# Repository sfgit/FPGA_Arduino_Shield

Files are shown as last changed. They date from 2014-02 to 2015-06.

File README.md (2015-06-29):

FPGA_Arduino_Shield
===================

**WIP** FPGA-based shield for Arduino (Standard UNO Connector pinout should support any Arduino with similar pinout)

NOTE:  It is my intent that the final design will work independently from the Arduino, so an Arduino would not be required to explore FPGA awesomeness.  That said, you may require a JTAG programmer or other device to program the SPI flash on the board.  Target pricing for this board is $30.  

Project Details:

This project is an effort to build a Xilinx Spartan 6 LX9 FPGA "shield" for the various 
Arduino development boards.  This board will also stand-alone, thus you will not require
the arduino to program and play with the FPGA.  

From the top level, the FPGA uses SPI configuration flash for it's in-system programming.
Also JTAG.  Thus if you program the flash, reboot the FPGA, it will load its config via
the flash.  This enables in-system, "asynchronous" reprogramming out-of-step with 
the overall system (arduino can keep running, as can any peripherals that are not a part
of the FPGA itself or FPGA subsystem).  This is super cool because it means that you might then 
use something like an SDCard or even TCP/IP comms to download new "hardware" configurations to
the FPGA and deploy them.  Thus, it may be possible to truly deploy new hardware remotely without
the need to crack into the case.  Awesomeness.  

In its simplest form this is the ultimate Arduino IO expander.  At it's most sophisticated, the
fpga has the capability to run it's own processor(s), it's own peripherals, and serve as its 
own system (the FPGA becoming the more prominent part of the system).  FPGAs are great for complex
parallel operations including DSP operations, audio, video, bitminer, etc. that an OTS CPU may not 
be suited for.  

Project details are available at:  hackaday.io/matt and the design files are starting
to trickle in here.  Regular revisions to the schematics are rolling in as changes are made and 
the structure of the project may change dramatically over time.  This means some design files 
may vanish.  If you need access to them, roll back.  If you have questions, please ask.  If 
you would like a board when it's built, let me know and we'll work something out.

Regarding Licensing:

These files are provided under the GNU General Public License Version 3 as found at http://opensource.org/licenses/lgpl-3.0.html. 

My personal warning (if you've gotten this far, you are better than me...read this last bit then go somewhere and do soemthing interesting):

BE CAREFUL.  Electronics and electronic design is dangerous and you can hurt yourself if you do it wrong.  I make mistakes.  We all do.  Eventually.  I have hurt myself as have my friends and we do not go around pointing fingers at people who build cool stuff, even if their ideas and projects end up hurting us.  Even when it was THEIR mistake in THEIR files.  I chose to do it, knowing the risks inherent in that.  It comes with the territory.  

Allow me to be free to be creative and build stuff and I will continue to share what I build.  Restrict that by blaming me when you set your cat's hair on fire or electrocute yourself or your wife or your kid or your iguana and you threaten the free flow of thoughts and ideas and information.  Tread carefully and only accept risks you can live with.

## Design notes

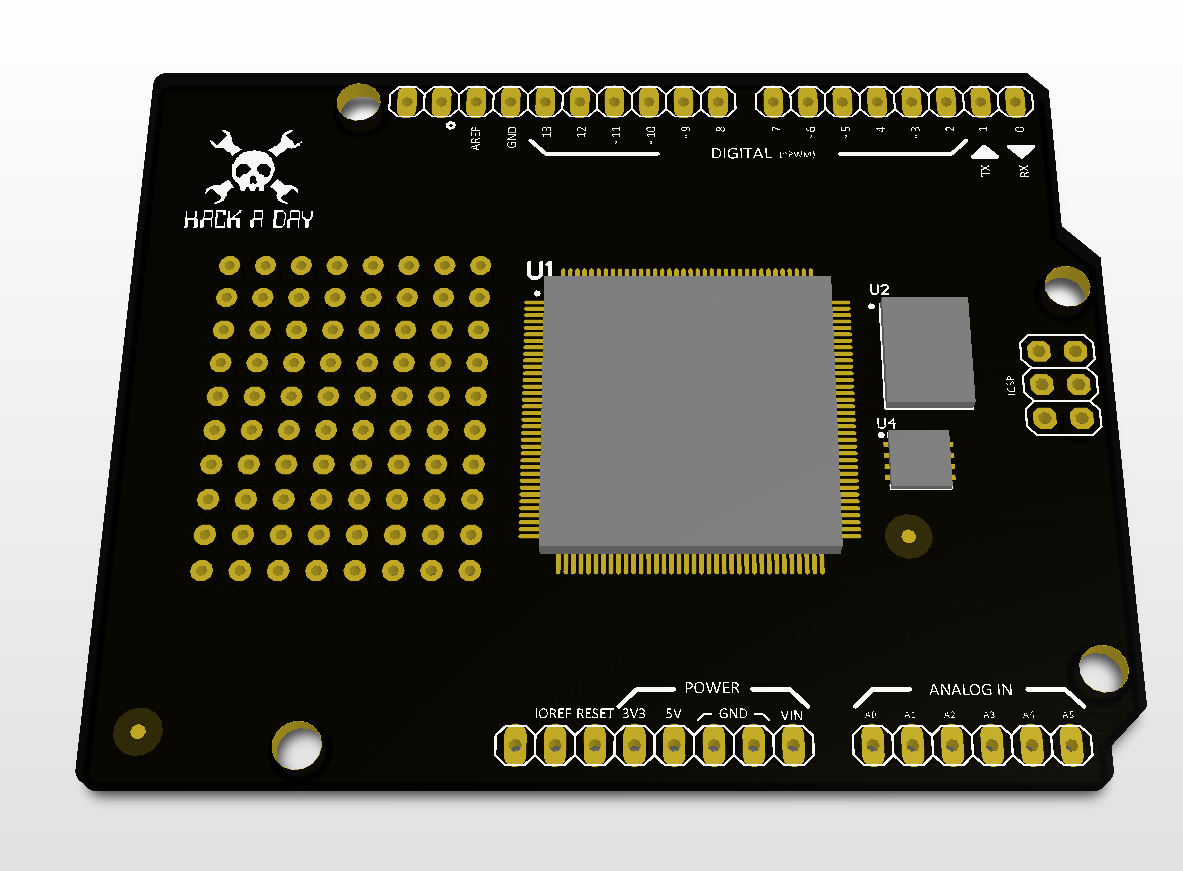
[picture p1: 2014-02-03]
Images/FPGA_Arduino.PNG

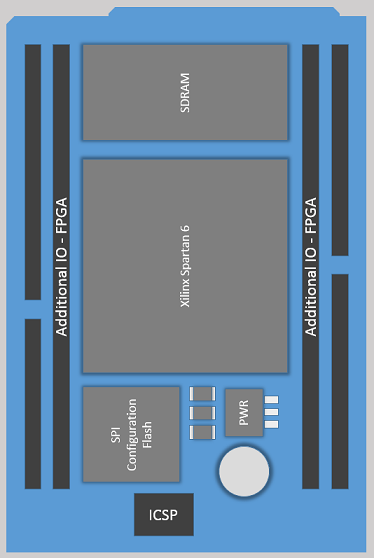
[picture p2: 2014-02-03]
Images/FPGA_Board_PPT_PIC_3_sm.png

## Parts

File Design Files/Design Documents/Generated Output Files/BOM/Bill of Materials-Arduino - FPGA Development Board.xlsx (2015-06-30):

Quantity | Designator | Manufacturer_PN | LibRef | Comment | Description | Footprint | Value
1 | J5 | 67997-210HLF | Header 5X2 | Header 5X2 | Header, 5-Pin, Dual row | HDR2X5
1 | J15 | 68000-404HLF | 4-POS-HDR | 4-POS VERTICAL HEADER | 4-POS VERTICAL HEADER | HDR1X4
1 | J1 | 68000-406HLF | HDR1X6X1 | HDR1X6X1 |  | HDR1X6
3 | J2, J3, J4 | 68000-406HLF | 6-POS-HDR | 6-POS VERTICAL HEADER | 6-POS VERTICAL HEADER | HDR1X6
3 | J12, J13, J14 | 71417-103HLF | 3-WAY JUMPER | 3-WAY JUMPER | 3-Way Jumper - Center Output | HDR1X3
1 | SW1 | ADTSM32RVTR |  | ADTSM32RVTR | ADTSM32RVTR SWITCH, TACTILE, SPST-NO, 50mA, 12VDC SMD | ADTSM32RVTR
1 | U6 | AP2114H-3.3TRG1 | AP2114H-3.3TRG1 | AP2114H-3.3TRG1 | AP2114, 1A Low Dropout Positive Fixed 3V3 Regulator | SOT230P700X180-4L
1 | LED4 | APT1608SGC |  | LED_GREEN_APT1608SGC | SMD 0603 LED, GREEN | LED0603
7 | C1, C22, C25, C30, C35, C39, C101 | C0402C104K8PACTU | CAP 100nF 16V ±10% 0402 (1005 Metric) Thickness 0.6mm SMD | CAP 100nF 16V 0402(1005) |  | CAPC0402(1005)60_L | 100nF
1 | C60 | C0402C104K8PACTU | CMP-1034-02064-1 | CAP 100nF 10V 0402(1005) | CAP 100nF 10V ±5% 0402 (1005 Metric) Thickness 0.6mm SMD | CAPC0402(1005)60_L | 100nF
1 | C37 | C0603C225K4PACTU | CMP-1035-02762-1 | CAP 2.2uF 16V 0603(1608) | CAP 2.2uF 16V ±10% 0603 (1608 Metric) Thickness 0.55mm SMD | CAPC0603(1608)55_L | 2.2uF
1 | C36 | C1005X5R1C105K050BC | CMP-1034-02119-1 | CAP 1uF 16V 0402(1005) | CAP 1uF 16V ±10% 0402 (1005 Metric) Thickness 0.6mm SMD | CAPC0402(1005)60_L | 1uF
1 | U7 | CAT6219-330TDGT3 | CAT6219-125TDGT3 | CAT6219-125TDGT3 | Fixed Low Drop Positive Voltage Regulator, 1.2V 5-Pin TSOT-23, Tape and Reel | ONSC-SOT23-5_M
16 | C2, C5, C6, C7, C8, C9, C10, C11, C12, C13, C14, C15, C18, C21, C33, C34 | CC0603KRX5R6BB475 | CAP 4.7uF 10V ±10% 0603 (1608 Metric) Thickness 0.55mm SMD | CAP 4.7uF 10V 0603(1608) |  | CAPC0603(1608)55_L | 4.7uF
1 | SW2 | CHS-04TA | CHS-04TA | CHS-04TA | SWITCH DIP 4-POS SLIDE SMD 6V | CHS-04A1
1 | J11 | CP-102AH-ND | POWER-CONNECTOR-3 | PWR CONNECTOR | Connector, 3 Conductor Power Jack | PJ-102AH
1 | R4 | CR0402-FX-1001GLFDKR-ND | 0402 (1005 Metric) 1/16 W 1K 1 Thick Film Chip Resistor | 1K 1 0402 |  | RESC0402(1005)40_L | 1K
14 | R2, R5, R6, R14, R15, R17, R18, R19, R20, R21, R30, R31, R32, R33 | CR0402-FX-4701GLFDKR-ND | 0402 (1005 Metric) 1/16 W 4K7 1 Thick Film Chip Resistor | 4K7 1 0402 |  | RESC0402(1005)40_L | 4K7
2 | R7, R8 | CR0402-FX-4701GLFDKR-ND | 0402 (1005 Metric) 1/16 W 4K7 1 Thick Film Chip Resistor | 4K7 |  | RESC0402(1005)40_L | 4K7
2 | R1, R3 | CR0603-FX-1000ELFDKR-ND | 0402 (1005 Metric) 1/16 W 100R 1 Thick Film Chip Resistor | 100R 1 0402 |  | RESC0402(1005)40_L | 100R
1 | J6 | DNP | Header 6 | Header 6 | Header, 6-Pin | 1X06
2 | J7, J8 | DNP | Header 8 | Header 8 | Header, 8-Pin | 1X08
1 | J9 | DNP | Header 10 | Header 10 | Header, 10-Pin | 1X10@1
1 | J10 | DNP | Header 3X2 | Header 3X2 | Header, 3-Pin, Dual row | 2X03
3 | C31, C32, C38 | GRM155R61C103KA01D | CMP-1034-01875-1 | CAP 10nF 16V 0402(1005) | CAP 10nF 16V ±10% 0402 (1005 Metric) Thickness 0.33mm SMD | CAPC0402(1005)33_L | 10nF
1 | U5 | IS61WV12816DBLL-10BLI | CMP-0513-00111-1 | IS61WV12816DBLL-10BLI | 2 M High Speed Asynchronous CMOS SRAM, 128 K x 16, -40 to 85 degC, 48-Pin BGA (TF-BGA-48), Pb-Free | ISSI-TF-BGA-48-6000X8000DE
1 | X2 | KC5032A20.0000CM0E00 | OSCILLATOR 20.0000MHZ SMD | KC5032A20.0000CM0E00 |  | HOSC-L500HW320H105-4_2
1 | U4 | LM1086ILD-3.3/NOPB | CMP-0062-01489-2 | LM1086ILD-3.3/NOPB | 1.5A Low Dropout Positive Regulators, 8-pin LLP, Pb-Free | LDC08A
10 | C3, C4, C16, C17, C19, C20, C26, C27, C28, C29 | LMK105BJ474KV-F | CAP 470nF 10V ±10% 0402 (1005 Metric) Thickness 0.6mm SMD | CAP 470nF 10V 0402(1005) |  | CAPC0402(1005)60_L | 470nF
5 | LED0, LED1, LED2, LED3, LED5 | LTST-C190KRKT | CMP-0201-0013 | 0402-LED-RED | 0402 LED,RED | LED_0402
5 | PWR2, PWR3, PWR4, PWR5, PWR6 | M20-9770246 | JMP1X2 | Jumper | Standard 2 Pin Jumper, 100mil spacing | JMP1X2
1 | R70 | RC0402FR-0756RL | CMP-1011-00369-1 | 56R 1% 0402(1005) | 56R 0.063W 1% 0402 (1005 Metric) SMD | RESC0402(1005)_L | 56R
5 | R16, R23, R25, R28, R34 | RC1005F271CS | CMP-0503-0059 | 270R 1 0402 | 0402 (1005 Metric) 1/16 W 270R 1 Thick Film Chip Resistor | RESC0402(1005)40_L | 270R
9 | R9, R10, R11, R12, R13, R24, R26, R27, R29 | RC1005F330CS | 0402 (1005 Metric) 1/16 W 33R 1 Thick Film Chip Resistor | 33R 1 0402 |  | RESC0402(1005)40_L | 33R
1 | R22 | RC1005F331CS | 0402 (1005 Metric) 1/16 W 330R 1 Thick Film Chip Resistor | 330R 1 0402 |  | RESC0402(1005)40_L | 330R
1 | D1 | S1G | S1G | S1G | Fairchild S1G General Purpose Rectifier | DO-214AC
1 | U2 | S25FL216K0PMFI041 | S25FL216K0PMFI041 | S25FL216K0PMFI041 | 16-Mbit 3.0V Serial Flash Memory with Uniform 4 kB Sectors | SPANSION-SOIC127P600X175-8M
2 | U8, U9 | SN74CBTD3861PWR | SN74CBTD3384CPWR | SN74CBTD3384CPWR | 10-BIT FET BUS SWITCH WITH LEVEL SHIFTING | TSOP65P620X120-24N
1 | U3 | SN74CBTLV3257DBQR | CMP-0267-00001-1 | SN74CBTLV3257DBQR | Low-Voltage 4-Bit 1-Of-2 FET Multiplexer/Demultiplexer, 16-pin SOP (DBQ16) | TI-DBQ16_N
1 | U15 | SN74LVC2G34DCKR | SN74LVC2G34DCKR | SN74LVC2G34DCKR | IC BUFFER DUAL NON-INV SC706 | TI-DCK6_L
2 | C23, C24 | TAJB106K020R | CMP-0279-00001-1 | TAJB106K020R | Capacitor, Tantalum, 10uF 10% 20V MCCT-B (3528) | AVX-CAPC3528_V
4 | TP1, TP2, TP3, TP4 | TESTPOINT | TESTPOINT_TH | TESTPOINT_TH |  | TESTPOINT_TH
1 | U1 | XC6SLX9-2TQG144C | CMP-0067-00454-1 | XC6SLX9-2TQG144C | Spartan-6 LX 1.2V FPGA, 102 User I/Os, 144-Pin TQFP (0.5mm Pitch), Speed Grade 2, Commercial Grade, Pb-Free | TQG144_N

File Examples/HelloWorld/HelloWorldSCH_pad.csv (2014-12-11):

#Release 14.7 - par P.20131013 (nt64)
#Copyright (c) 1995-2013 Xilinx | Inc. All rights reserved.
#Tue Dec 09 11:33:54 2014
#
## NOTE: This file is designed to be imported into a spreadsheet program
# such as Microsoft Excel for viewing | printing and sorting. The
# character is used as the data field separator. This file is also designed
# to support parsing.
#
#INPUT FILE: HelloWorldSCH_map.ncd
#OUTPUT FILE: HelloWorldSCH_pad.csv
#PART TYPE: xc6slx9
#SPEED GRADE: -2
#PACKAGE: tqg144
#
# Pinout by Pin Number:
#
# ----- | ----- | ----- | ----- | ----- | ----- | ----- | ----- | ----- | ----- | ----- | ----- | ----- | ----- | -----
Pin Number | Signal Name | Pin Usage | Pin Name | Direction | IO Standard | IO Bank Number | Drive (mA) | Slew Rate | Termination | IOB Delay | Voltage | Constraint | IO Register | Signal Integrity
P1 |  | IOBS | IO_L83N_VREF_3 | UNUSED |  | 3
P2 |  | IOBM | IO_L83P_3 | UNUSED |  | 3
P3 |  |  | GND
P4 |  |  | VCCO_3 |  |  | 3 |  |  |  |  | any******
P5 |  | IOBS | IO_L52N_3 | UNUSED |  | 3
P6 |  | IOBM | IO_L52P_3 | UNUSED |  | 3
P7 |  | IOBS | IO_L51N_3 | UNUSED |  | 3
P8 |  | IOBM | IO_L51P_3 | UNUSED |  | 3
P9 |  | IOBS | IO_L50N_3 | UNUSED |  | 3
P10 |  | IOBM | IO_L50P_3 | UNUSED |  | 3
P11 |  | IOBS | IO_L49N_3 | UNUSED |  | 3
P12 |  | IOBM | IO_L49P_3 | UNUSED |  | 3
P13 |  |  | GND
P14 |  | IOBS | IO_L44N_GCLK20_3 | UNUSED |  | 3
P15 |  | IOBM | IO_L44P_GCLK21_3 | UNUSED |  | 3
P16 |  | IOBS | IO_L43N_GCLK22_IRDY2_3 | UNUSED |  | 3
P17 |  | IOBM | IO_L43P_GCLK23_3 | UNUSED |  | 3
P18 |  |  | VCCO_3 |  |  | 3 |  |  |  |  | any******
P19 |  |  | VCCINT |  |  |  |  |  |  |  | 1.2
P20 |  |  | VCCAUX |  |  |  |  |  |  |  | 2.5
P21 |  | IOBS | IO_L42N_GCLK24_3 | UNUSED |  | 3
P22 |  | IOBM | IO_L42P_GCLK25_TRDY2_3 | UNUSED |  | 3
P23 |  | IOBS | IO_L41N_GCLK26_3 | UNUSED |  | 3
P24 |  | IOBM | IO_L41P_GCLK27_3 | UNUSED |  | 3
P25 |  |  | GND
P26 |  | IOBS | IO_L37N_3 | UNUSED |  | 3
P27 |  | IOBM | IO_L37P_3 | UNUSED |  | 3
P28 |  |  | VCCINT |  |  |  |  |  |  |  | 1.2
P29 |  | IOBS | IO_L36N_3 | UNUSED |  | 3
P30 |  | IOBM | IO_L36P_3 | UNUSED |  | 3
P31 |  |  | VCCO_3 |  |  | 3 |  |  |  |  | any******
P32 |  | IOBS | IO_L2N_3 | UNUSED |  | 3
P33 |  | IOBM | IO_L2P_3 | UNUSED |  | 3
P34 |  | IOBS | IO_L1N_VREF_3 | UNUSED |  | 3
P35 |  | IOBM | IO_L1P_3 | UNUSED |  | 3
P36 |  |  | VCCAUX |  |  |  |  |  |  |  | 2.5
P37 |  |  | PROGRAM_B_2
P38 |  | IOBS | IO_L65N_CSO_B_2 | UNUSED |  | 2
P39 |  | IOBM | IO_L65P_INIT_B_2 | UNUSED |  | 2
P40 |  | IOBS | IO_L64N_D9_2 | UNUSED |  | 2
P41 |  | IOBM | IO_L64P_D8_2 | UNUSED |  | 2
P42 |  |  | VCCO_2 |  |  | 2 |  |  |  |  | any******
P43 |  | IOBS | IO_L62N_D6_2 | UNUSED |  | 2
P44 |  | IOBM | IO_L62P_D5_2 | UNUSED |  | 2
P45 |  | IOBS | IO_L49N_D4_2 | UNUSED |  | 2
P46 |  | IOBM | IO_L49P_D3_2 | UNUSED |  | 2
P47 |  | IOBS | IO_L48N_RDWR_B_VREF_2 | UNUSED |  | 2
P48 |  | IOBM | IO_L48P_D7_2 | UNUSED |  | 2
P49 |  |  | GND
P50 |  | IOBS | IO_L31N_GCLK30_D15_2 | UNUSED |  | 2
P51 |  | IOBM | IO_L31P_GCLK31_D14_2 | UNUSED |  | 2
P52 |  |  | VCCINT |  |  |  |  |  |  |  | 1.2
P53 |  |  | VCCAUX |  |  |  |  |  |  |  | 2.5
P54 |  |  | GND
P55 |  | IOBS | IO_L30N_GCLK0_USERCCLK_2 | UNUSED |  | 2
P56 | CLK_BRD | IOB | IO_L30P_GCLK1_D13_2 | INPUT | LVCMOS25* | 2 |  |  |  | NONE |  | LOCATED | NO | NONE
P57 |  | IOBS | IO_L14N_D12_2 | UNUSED |  | 2
P58 |  | IOBM | IO_L14P_D11_2 | UNUSED |  | 2
P59 |  | IOBS | IO_L13N_D10_2 | UNUSED |  | 2
P60 |  | IOBM | IO_L13P_M1_2 | UNUSED |  | 2
P61 |  | IOBS | IO_L12N_D2_MISO3_2 | UNUSED |  | 2
P62 |  | IOBM | IO_L12P_D1_MISO2_2 | UNUSED |  | 2
P63 |  |  | VCCO_2 |  |  | 2 |  |  |  |  | any******
P64 |  | IOBS | IO_L3N_MOSI_CSI_B_MISO0_2 | UNUSED |  | 2
P65 |  | IOBM | IO_L3P_D0_DIN_MISO_MISO1_2 | UNUSED |  | 2
P66 |  | IOBS | IO_L2N_CMPMOSI_2 | UNUSED |  | 2
P67 |  | IOBM | IO_L2P_CMPCLK_2 | UNUSED |  | 2
P68 |  |  | GND
P69 |  | IOBS | IO_L1N_M0_CMPMISO_2 | UNUSED |  | 2
P70 |  | IOBM | IO_L1P_CCLK_2 | UNUSED |  | 2
P71 |  |  | DONE_2
P72 |  |  | CMPCS_B_2
P73 |  |  | SUSPEND
P74 |  | IOBS | IO_L74N_DOUT_BUSY_1 | UNUSED |  | 1
P75 |  | IOBM | IO_L74P_AWAKE_1 | UNUSED |  | 1
P76 |  |  | VCCO_1 |  |  | 1 |  |  |  |  | any******
P77 |  |  | GND
P78 |  | IOBS | IO_L47N_1 | UNUSED |  | 1
P79 |  | IOBM | IO_L47P_1 | UNUSED |  | 1
P80 |  | IOBS | IO_L46N_1 | UNUSED |  | 1
P81 |  | IOBM | IO_L46P_1 | UNUSED |  | 1
P82 |  | IOBS | IO_L45N_1 | UNUSED |  | 1
P83 |  | IOBM | IO_L45P_1 | UNUSED |  | 1
P84 |  | IOBS | IO_L43N_GCLK4_1 | UNUSED |  | 1
P85 |  | IOBM | IO_L43P_GCLK5_1 | UNUSED |  | 1
P86 |  |  | VCCO_1 |  |  | 1 |  |  |  |  | any******
P87 |  | IOBS | IO_L42N_GCLK6_TRDY1_1 | UNUSED |  | 1
P88 |  | IOBM | IO_L42P_GCLK7_1 | UNUSED |  | 1
P89 |  |  | VCCINT |  |  |  |  |  |  |  | 1.2
P90 |  |  | VCCAUX |  |  |  |  |  |  |  | 2.5
P91 |  |  | GND
P92 |  | IOBS | IO_L41N_GCLK8_1 | UNUSED |  | 1
P93 |  | IOBM | IO_L41P_GCLK9_IRDY1_1 | UNUSED |  | 1
P94 |  | IOBS | IO_L40N_GCLK10_1 | UNUSED |  | 1
P95 |  | IOBM | IO_L40P_GCLK11_1 | UNUSED |  | 1
P96 |  |  | GND
P97 |  | IOBS | IO_L34N_1 | UNUSED |  | 1
P98 |  | IOBM | IO_L34P_1 | UNUSED |  | 1
P99 |  | IOBS | IO_L33N_1 | UNUSED |  | 1
P100 |  | IOBM | IO_L33P_1 | UNUSED |  | 1
P101 |  | IOBS | IO_L32N_1 | UNUSED |  | 1
P102 |  | IOBM | IO_L32P_1 | UNUSED |  | 1
P103 |  |  | VCCO_1 |  |  | 1 |  |  |  |  | any******
P104 |  | IOBS | IO_L1N_VREF_1 | UNUSED |  | 1
P105 |  | IOBM | IO_L1P_1 | UNUSED |  | 1
P106 |  |  | TDO
P107 |  |  | TMS
P108 |  |  | GND
P109 |  |  | TCK
P110 |  |  | TDI
P111 |  | IOBS | IO_L66N_SCP0_0 | UNUSED |  | 0
P112 |  | IOBM | IO_L66P_SCP1_0 | UNUSED |  | 0
P113 |  |  | GND
P114 |  | IOBS | IO_L65N_SCP2_0 | UNUSED |  | 0
P115 |  | IOBM | IO_L65P_SCP3_0 | UNUSED |  | 0
P116 | UIO<3> | IOB | IO_L64N_SCP4_0 | OUTPUT | LVCMOS25* | 0 | 12 | SLOW |  |  |  | LOCATED | NO | NONE
P117 |  | IOBM | IO_L64P_SCP5_0 | UNUSED |  | 0
P118 |  | IOBS | IO_L63N_SCP6_0 | UNUSED |  | 0
P119 |  | IOBM | IO_L63P_SCP7_0 | UNUSED |  | 0
P120 | UIO<2> | IOB | IO_L62N_VREF_0 | OUTPUT | LVCMOS25* | 0 | 12 | SLOW |  |  |  | LOCATED | NO | NONE
P121 |  | IOBM | IO_L62P_0 | UNUSED |  | 0
P122 |  |  | VCCO_0 |  |  | 0 |  |  |  |  | 2.50
P123 |  | IOBS | IO_L37N_GCLK12_0 | UNUSED |  | 0
P124 |  | IOBM | IO_L37P_GCLK13_0 | UNUSED |  | 0
P125 |  |  | VCCO_0 |  |  | 0 |  |  |  |  | 2.50
P126 | UIO<1> | IOB | IO_L36N_GCLK14_0 | OUTPUT | LVCMOS25* | 0 | 12 | SLOW |  |  |  | LOCATED | NO | NONE
P127 |  | IOBM | IO_L36P_GCLK15_0 | UNUSED |  | 0
P128 |  |  | VCCINT |  |  |  |  |  |  |  | 1.2
P129 |  |  | VCCAUX |  |  |  |  |  |  |  | 2.5
P130 |  |  | GND
P131 |  | IOBS | IO_L35N_GCLK16_0 | UNUSED |  | 0
P132 |  | IOBM | IO_L35P_GCLK17_0 | UNUSED |  | 0
P133 |  | IOBS | IO_L34N_GCLK18_0 | UNUSED |  | 0
P134 | UIO<0> | IOB | IO_L34P_GCLK19_0 | OUTPUT | LVCMOS25* | 0 | 12 | SLOW |  |  |  | LOCATED | NO | NONE
P135 |  |  | VCCO_0 |  |  | 0 |  |  |  |  | 2.50
P136 |  |  | GND
P137 |  | IOBS | IO_L4N_0 | UNUSED |  | 0
P138 |  | IOBM | IO_L4P_0 | UNUSED |  | 0
P139 |  | IOBS | IO_L3N_0 | UNUSED |  | 0
P140 |  | IOBM | IO_L3P_0 | UNUSED |  | 0
P141 |  | IOBS | IO_L2N_0 | UNUSED |  | 0
P142 |  | IOBM | IO_L2P_0 | UNUSED |  | 0
P143 |  | IOBS | IO_L1N_VREF_0 | UNUSED |  | 0
P144 |  | IOBM | IO_L1P_HSWAPEN_0 | UNUSED |  | 0
# ----- | ----- | ----- | ----- | ----- | ----- | ----- | ----- | ----- | ----- | ----- | ----- | ----- | ----- | -----
#
#* Default value.
#** This default Pullup/Pulldown value can be overridden in Bitgen.
#****** Special VCCO requirements may apply. Please consult the device
# family datasheet for specific guideline on VCCO requirements.
#
#
#

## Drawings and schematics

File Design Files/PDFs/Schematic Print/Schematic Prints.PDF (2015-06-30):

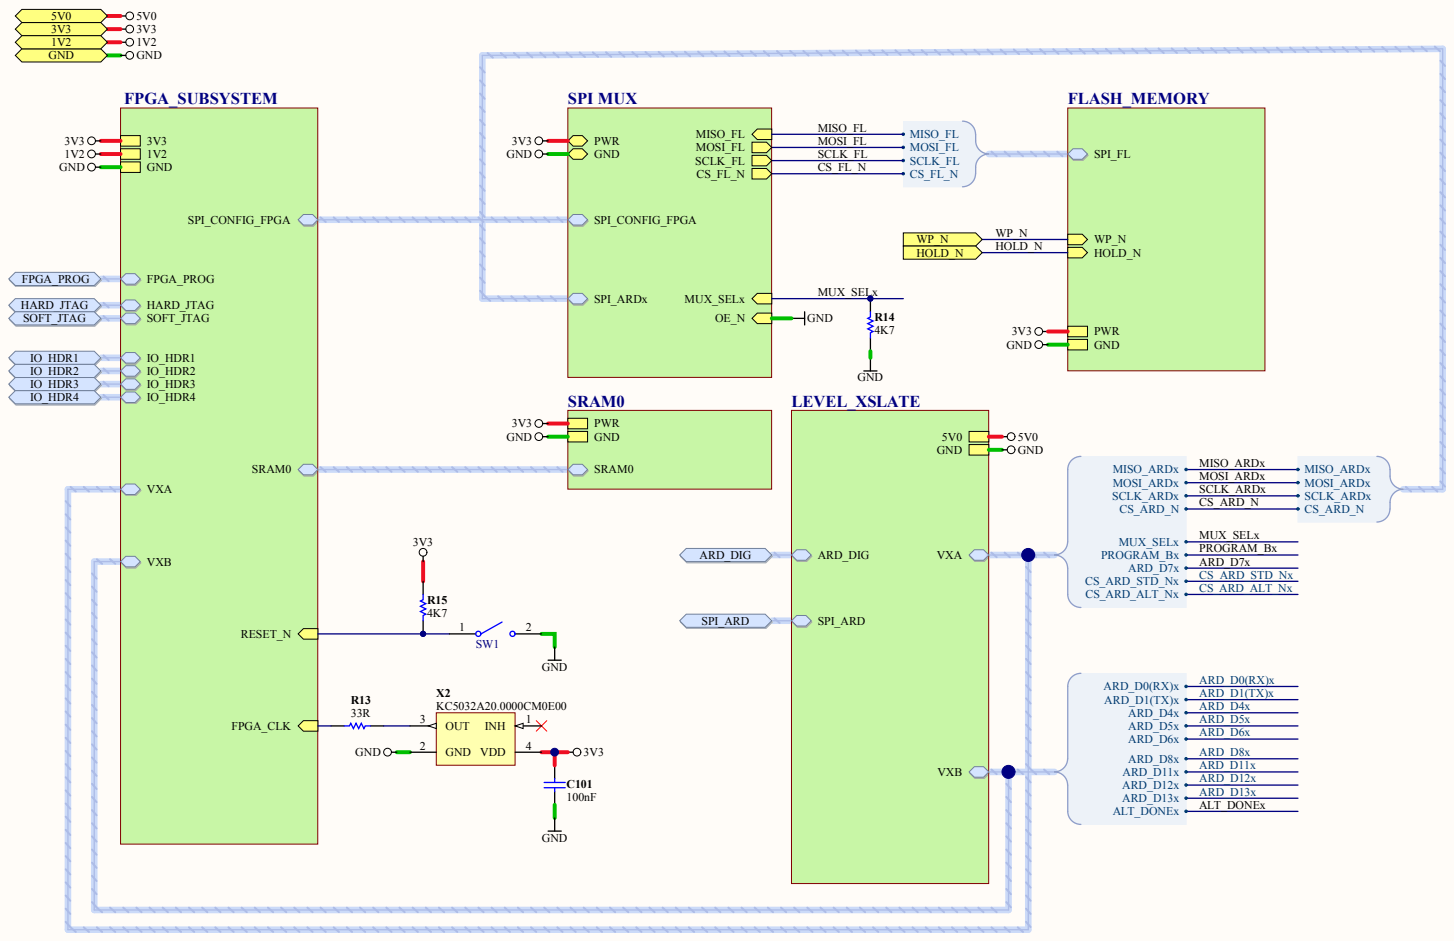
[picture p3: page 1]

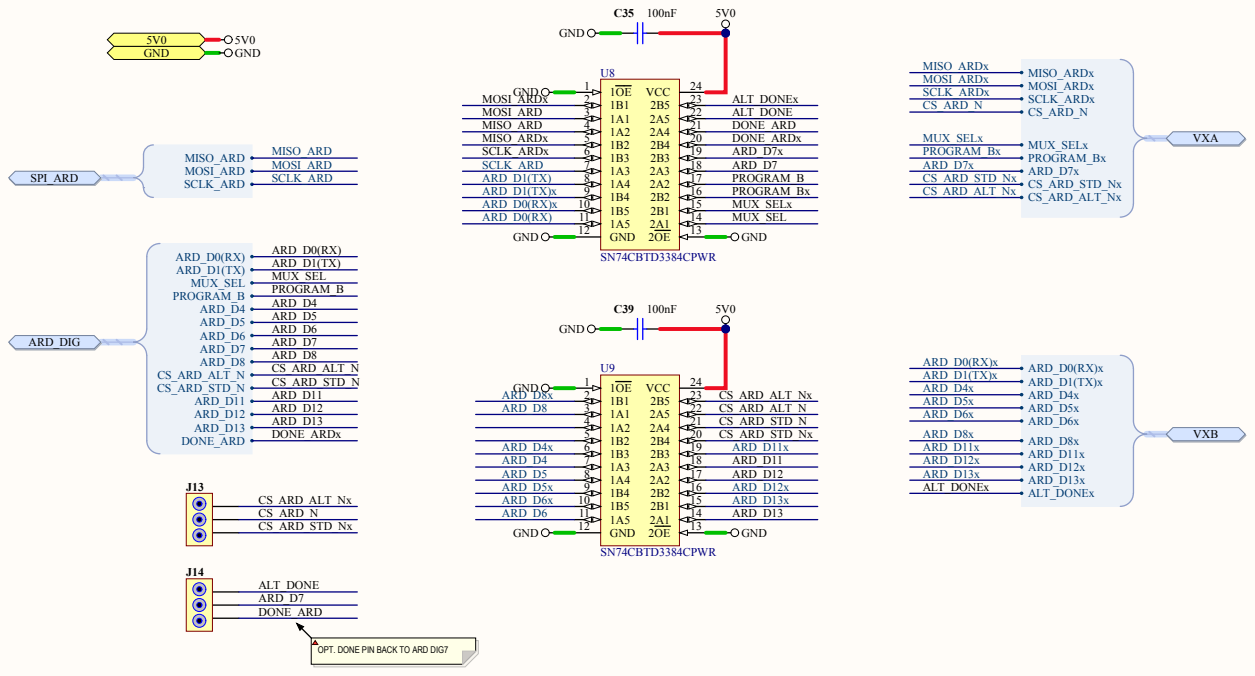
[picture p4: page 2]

OPT. DONE PIN BACK TO ARD DIG7

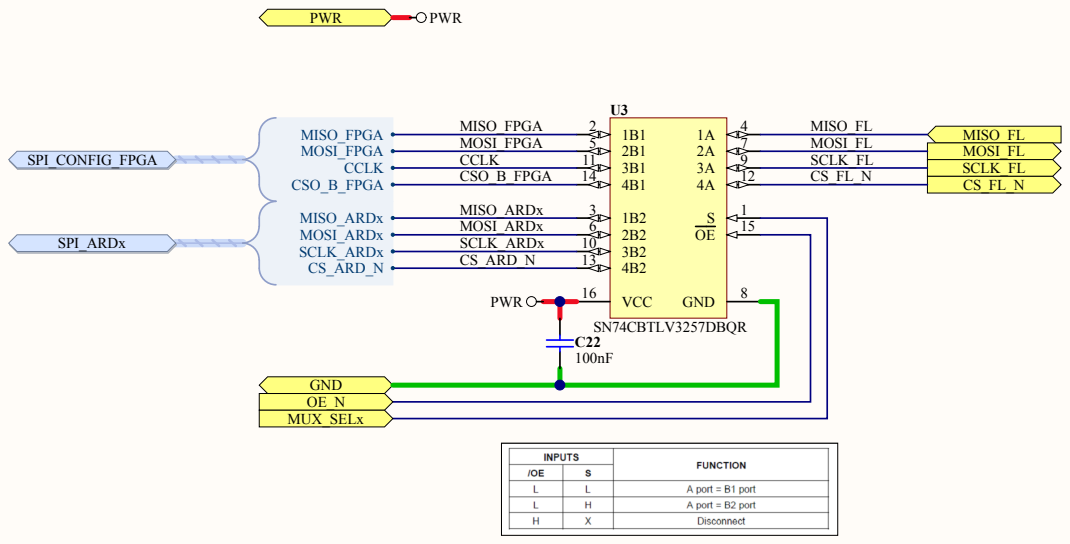
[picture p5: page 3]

MOSI_ARDx | 2B2 6 OE | 15
SCLK_ARDx | 3B2 10 GND | 8 VCC 16

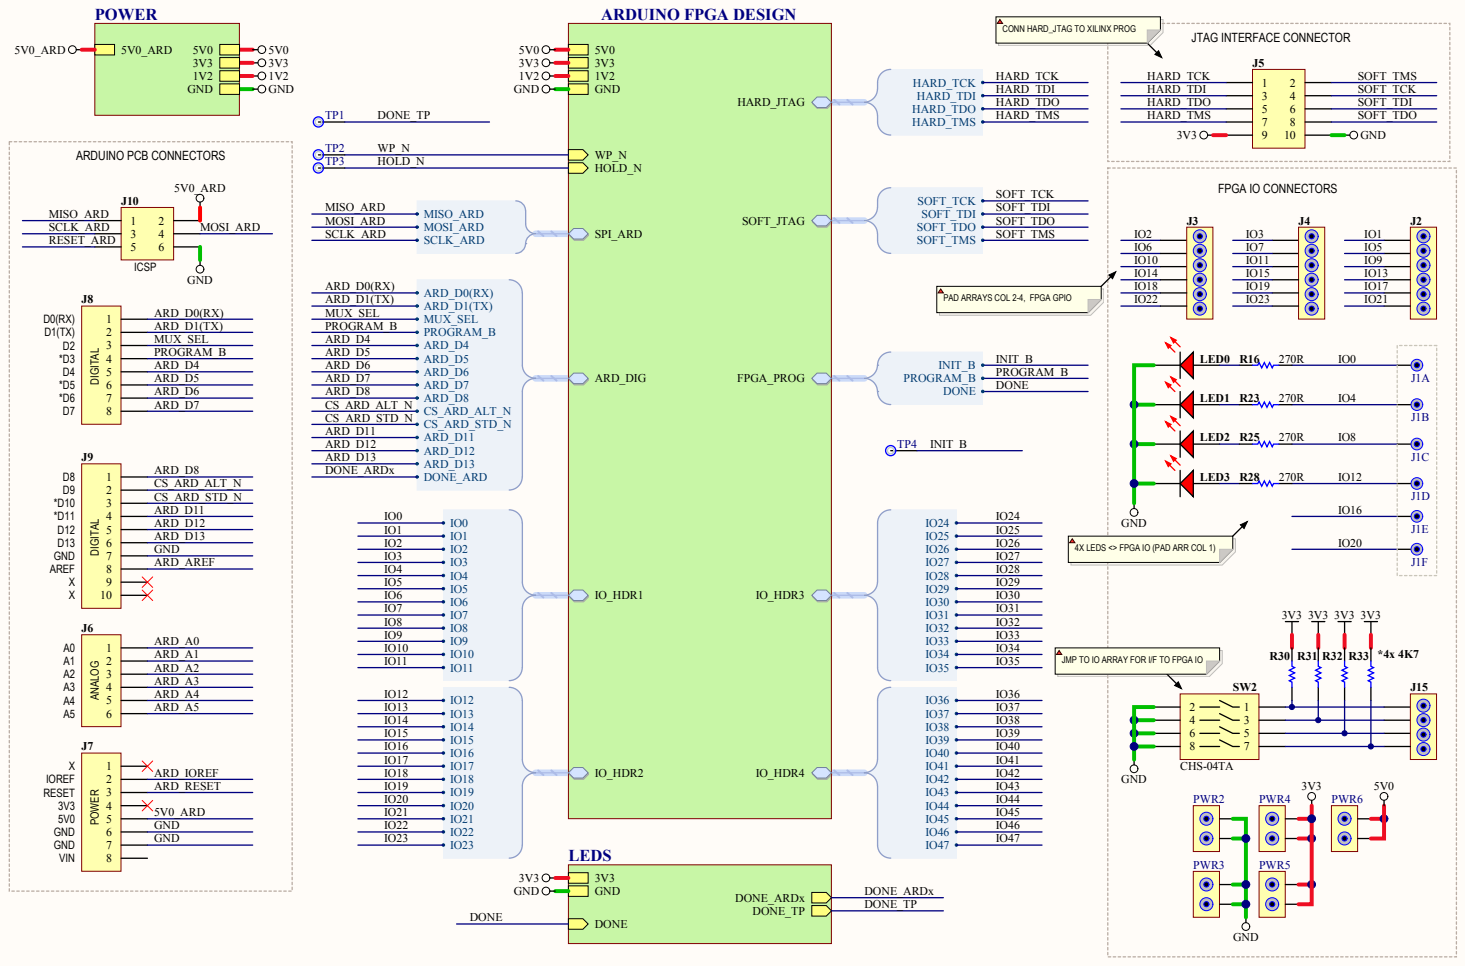
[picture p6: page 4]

CONN HARD_JTAG TO XILINX PROG

PAD ARRAYS COL 2-4, FPGA GPIO

4X LEDS <> FPGA IO (PAD ARR COL 1)

JMP TO IO ARRAY FOR I/F TO FPGA IO

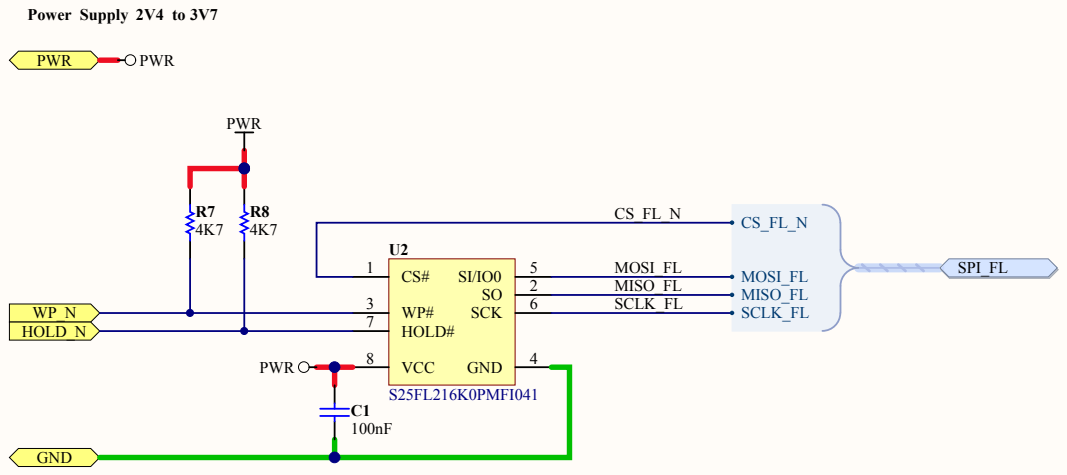
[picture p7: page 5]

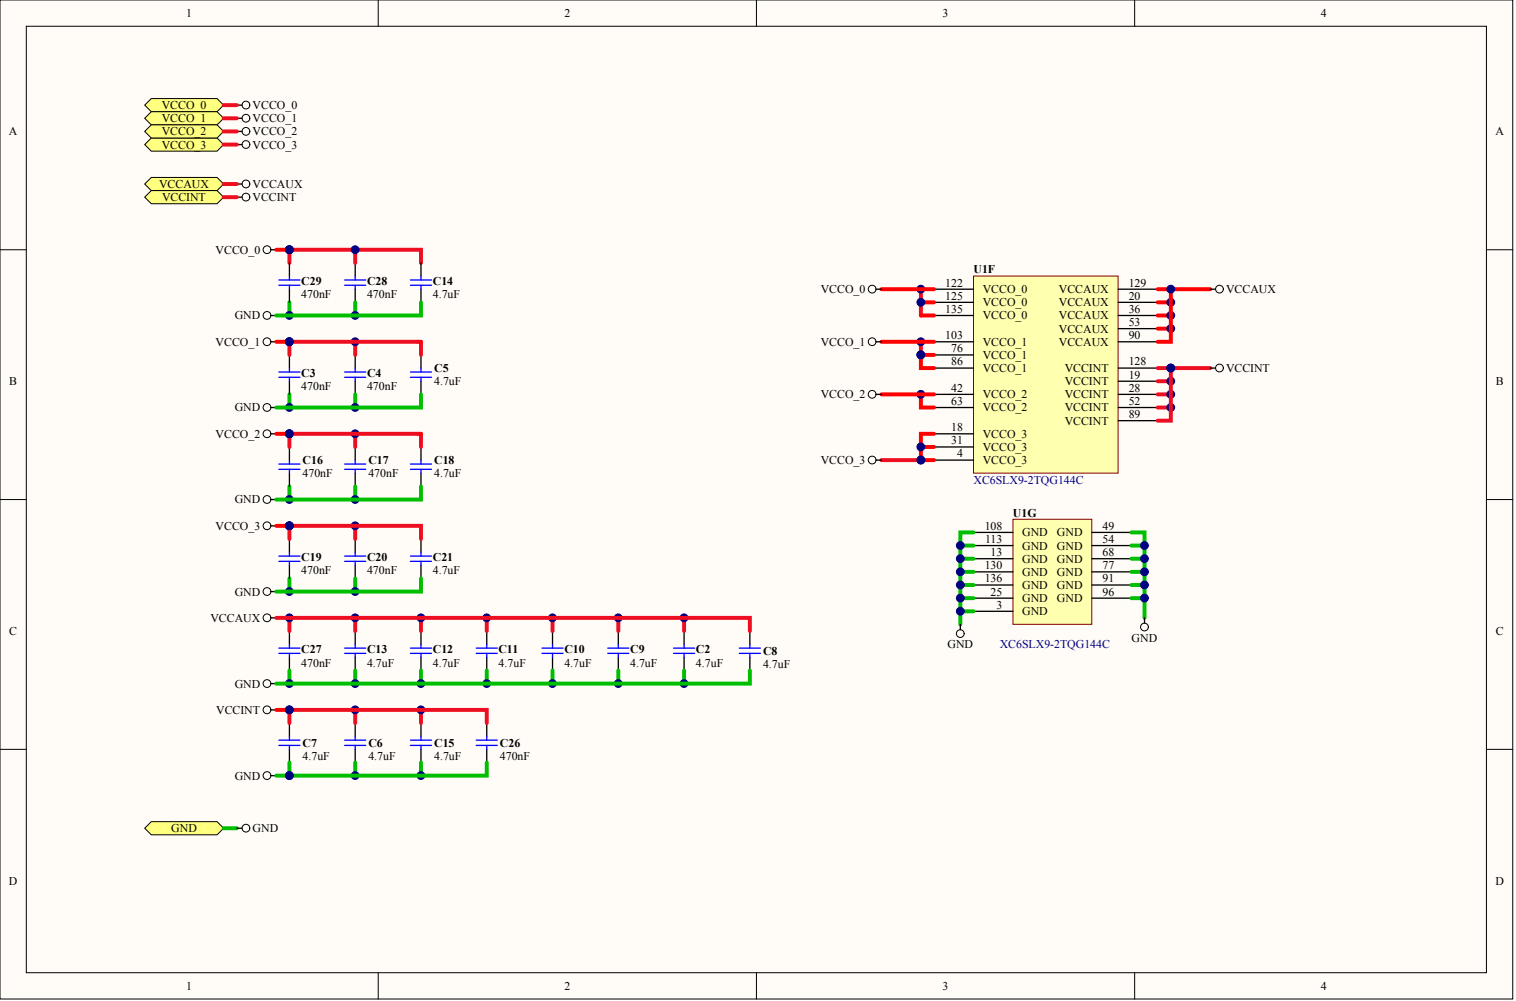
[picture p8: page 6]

VCCO_3 31
VCCO_3 4

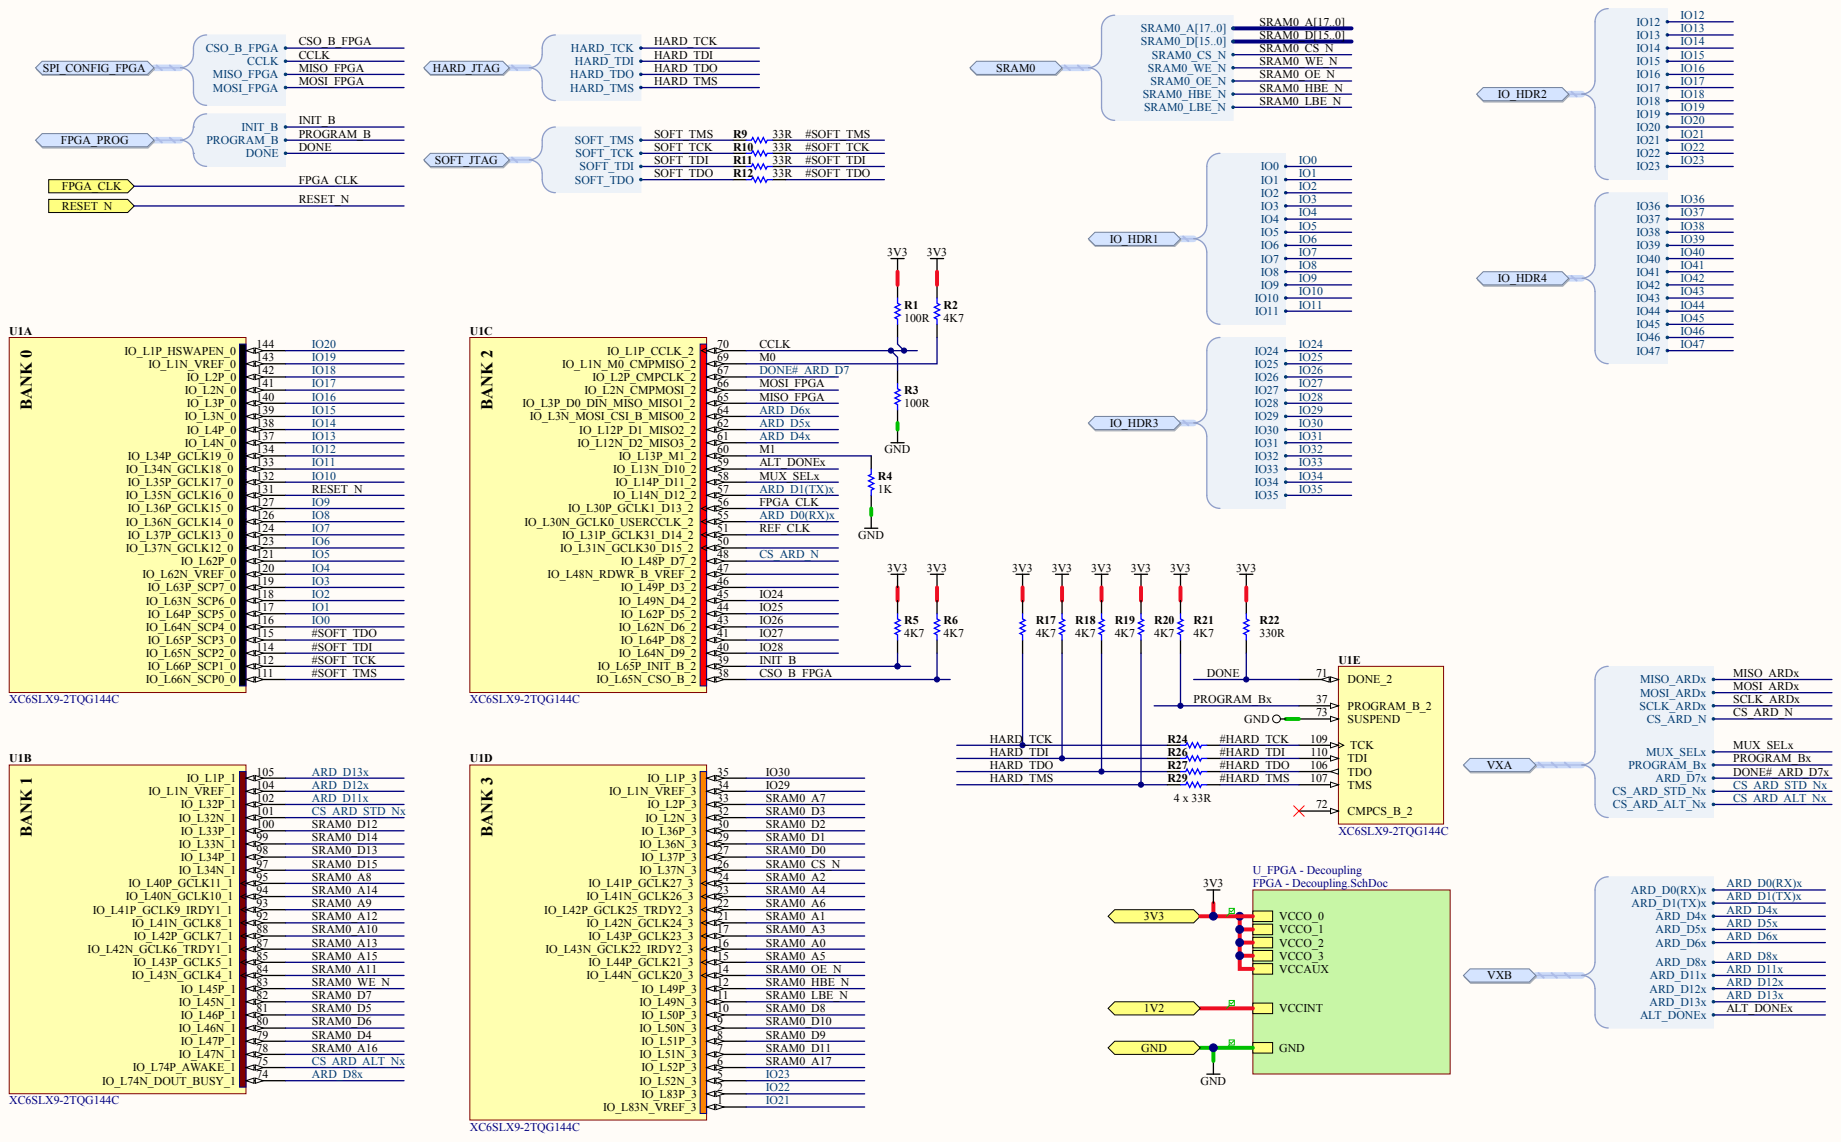
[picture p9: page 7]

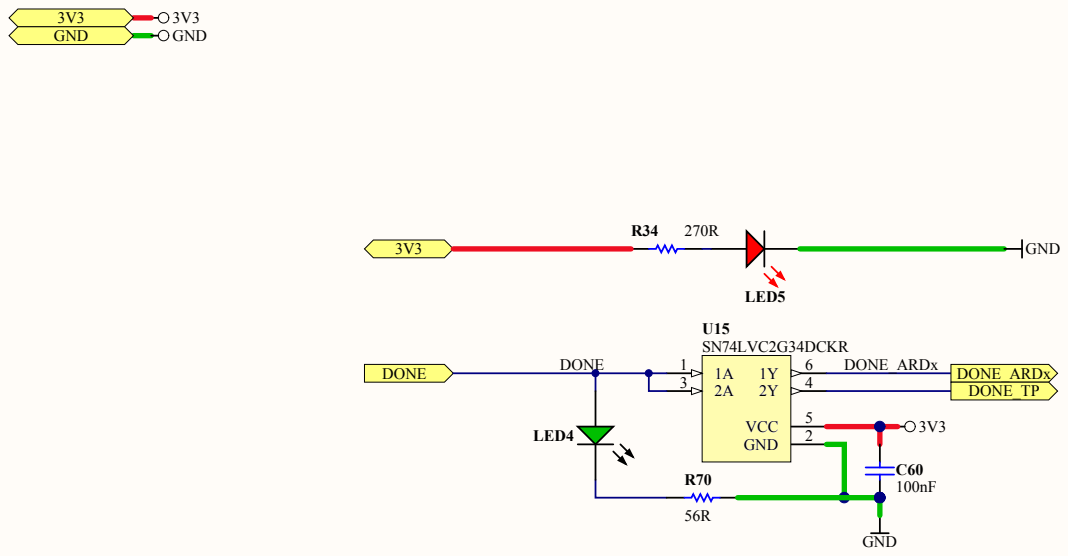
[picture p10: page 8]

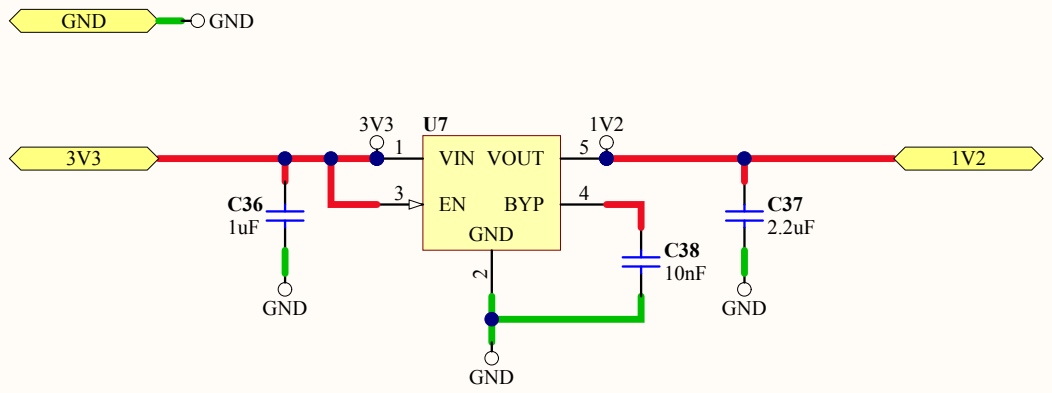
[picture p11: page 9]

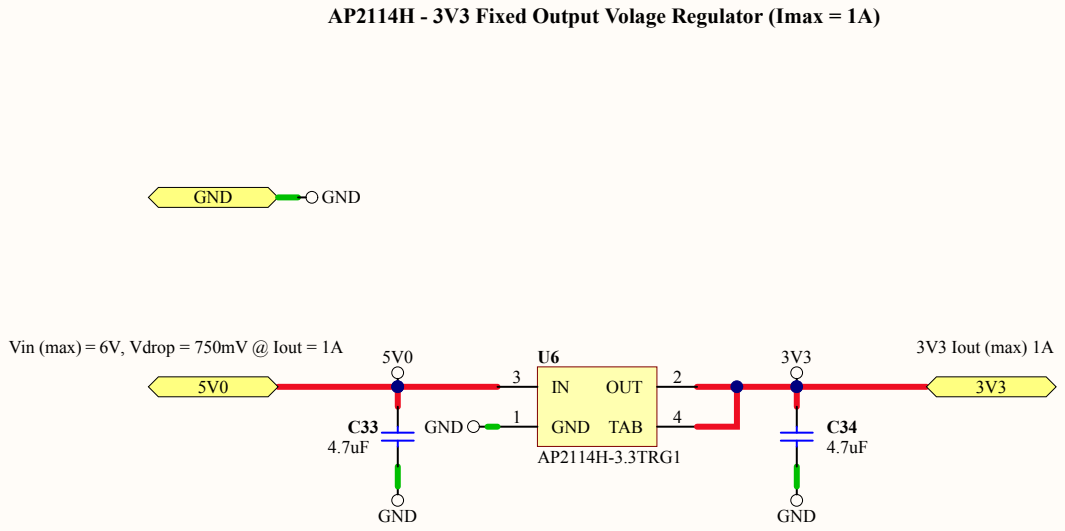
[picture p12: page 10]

AP2114H - 3V3 Fixed Output Volage Regulator (Imax = 1A)

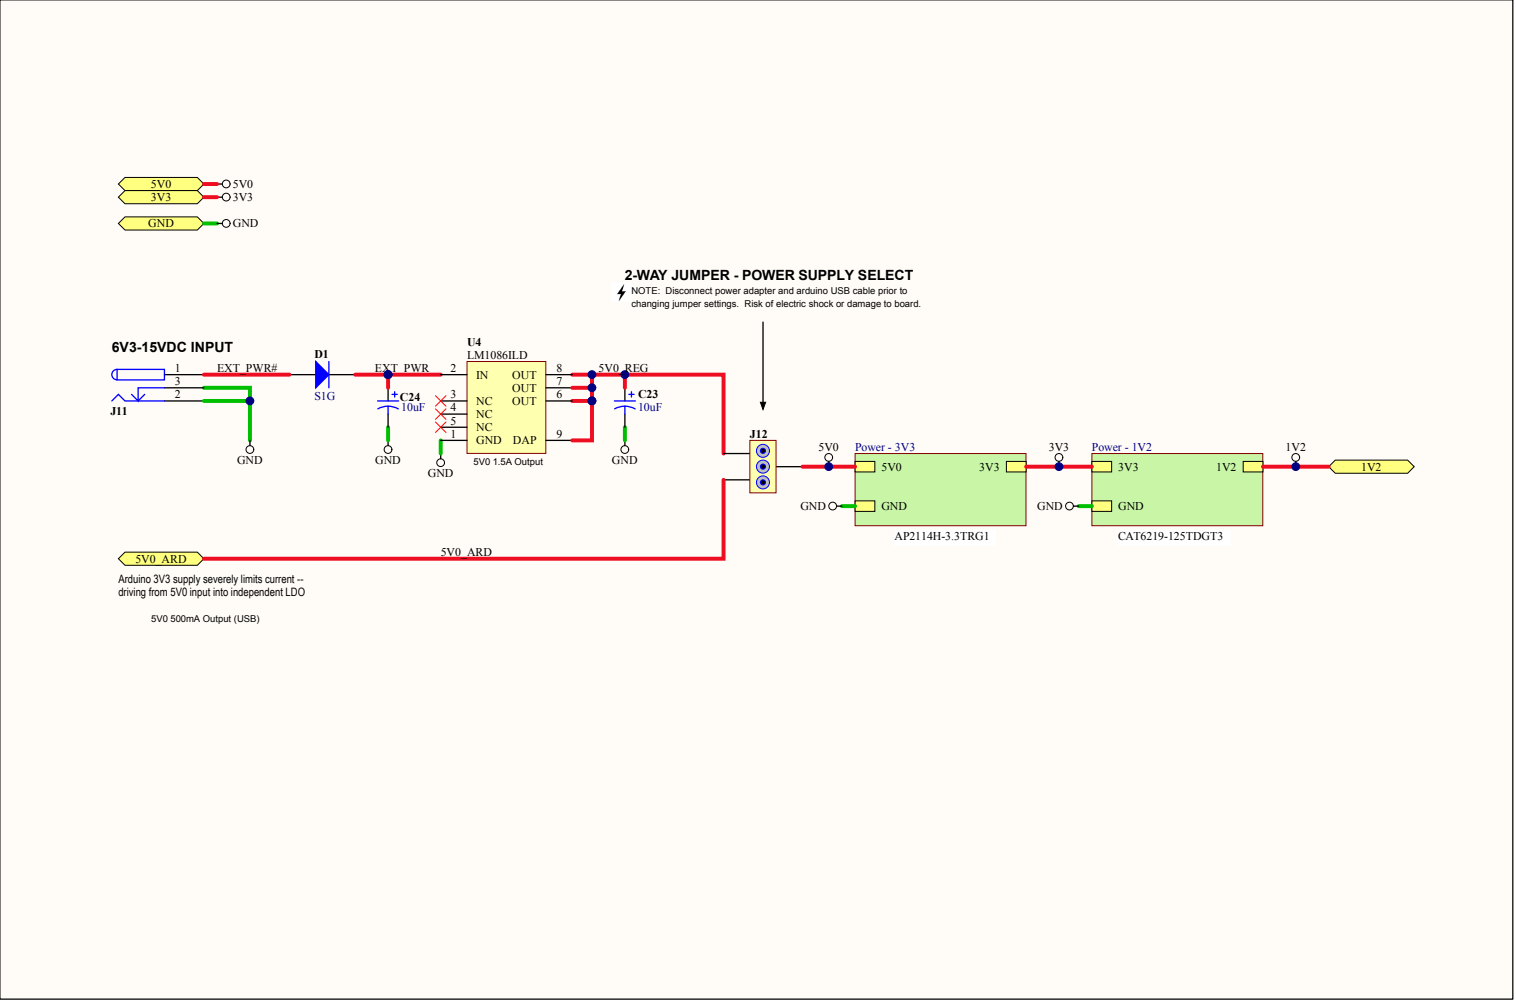
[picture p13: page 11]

2-WAY JUMPER - POWER SUPPLY SELECT

NOTE: Disconnect power adapter and arduino USB cable prior to
changing jumper settings. Risk of electric shock or damage to board.

5V0_ARD
Arduino 3V3 supply severely limits current --
driving from 5V0 input into independent LDO

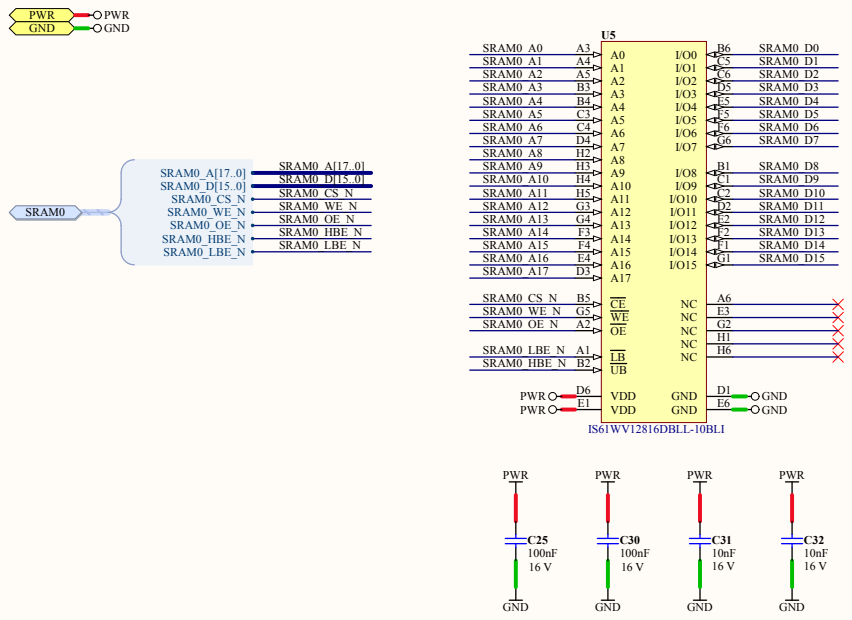
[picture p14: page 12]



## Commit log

2014-02-03 Uploaded some basic PCB footprints
    Upload FPs to have a look at the area constraints in the PCB and see
    what sort of area I have to work with. See the uploaded PCB file for
    reference. This is ONLY for reference. I will trash the board as the
    schematics are completed and I lay it all out.
    [ISSI-TF-BGA-48-6000X8000DE.PcbLib, TQG144_N.PcbLib]
2014-02-03 Upload rough PCB file
    Uploading a rough PCB file just to get a sense of board area
    requirements and how this might affect component choice. Do NOT use
    this PCB. It's just an Eagle import and no work has been done on the
    layout. Just a size-thing.
    [mB_arduino_board - ROUGH (do not use).PcbDoc]
2014-02-13 Uploading some preliminary schematics
    Uploading preliminary (WIP) schematics. Will also convert to PDF for
    those without Altium Designer Software.
    [Arduino - FPGA Development Board.PrjPcb, FPGA - Decoupling.SchDoc, FPGA - XC6SLX9-2TQG144C.schdoc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]
2014-02-13 Uploading PDF schematics for SPI flash and FPGA
    Uploading some PDFs of the SPI flash schematic and the FPGA schematic
    which is still very much a work in progress.
2014-03-02 JTAG Wiring Complete and Decoupling Completed
    This update includes the completion of the JTAG wiring and the
    decoupling as per the Xilinx recommendations in the layout guide. Video
    to follow found on youtube by searching technolomaniac.
    [FPGA - Decoupling.SchDoc, FPGA - XC6SLX9-2TQG144C.schdoc]
2014-03-02 Updated Schematics - Top Level, FPGA, Hierarchy
    Replaced the stand alone PDFs with a hierarchical PDF that includes the
    various sheets including the top-level breakout. Also showing a very
    basic PCB PDF to show how the breakout may go. Ignore the power
    components for the time being, this is WIP and needs to be sorted to
    support external power (stand alone), power from arduino USB and the
    arduino DC supply. All should be sorted in the next commit.
    [Arduino - FPGA Development Board.PrjPcb, Arduino FPGA Design.SchDoc, Arduino FPGA Power.SchDoc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]
2014-03-02 Added PCB PDF and showing a possible breakout
    Uploaded a PDF of the PCB and added a possible breakout schema for the
    PCB that includes the use of thru-hole pads to which headers can be
    soldered easily. Not set in stone but definitely reflecting this in the
    top level schematic.
    [Arduino_FPGA_Shield.PcbDoc, mB_arduino_board - ROUGH (do not use).PcbDoc]
2014-03-03 Reworked schematic - Added SPI MUX
    Reworked the schematic to add the SPI MUX and rework some of the bus
    naming and sheet to sheet connections. Intent to make things more
    readable and tidy up some of the connections, what-not. Still very much
    a work-in-progress but coming along nicely.
    [Arduino - FPGA Development Board.PrjPcb, Arduino FPGA Design.SchDoc, Arduino FPGA SPI MUX.SchDoc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]
2014-03-11 Uploading SPI MUX and SRAM Sheets
    Uploading numerous changes including changes to SPI MUX, some power
    supply stuff (WIP) and SRAM sheets. Also tons of cosmetic tweaks and
    optimizations.
    [Arduino - FPGA Development Board.PrjPcb, Arduino FPGA Design.SchDoc, Arduino FPGA SPI MUX.SchDoc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]
2014-03-11 Resized FPGA document
    [FPGA - XC6SLX9-2TQG144C.schdoc]
2014-03-11 Uploaded PDF schematic
2014-03-14 Completed PCB SRAM routing
    Completed routing of the SRAM on PCB. Not perfect just yet but coming
    along nicely. Also routed the two JTAG buses to the JTAG header.
    [Arduino_FPGA_Shield.PcbDoc]
2014-03-31 Completed Power Supply Design
    Uploaded completed power supply design to repo. Includes 5V 1.5A DC
    adapter (accepts 6.7-15V input), 3V3 1A supply, & 1V2 500mA supply (for
    FPGA core).
    [AP2114H-3.3TRG1.SchLib, Arduino - FPGA Development Board.PrjPcb, Arduino FPGA Design.SchDoc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]
2014-05-02 Release_Prototype_Files
    Completed a preliminary layout of PCB - releasing files to prototype
    today.
    [AP2114H-3.3TRG1.SchLib, Arduino - FPGA Development Board.PrjPcb, Arduino FPGA Top-Level Interface.SchDoc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]
2014-05-02 Released Gerber Drill and asstd Output Files
    Released the gerber files, ODB++ files, NC drill files, pick and place
    and more, all for prototype.
    [Arduino_FPGA_Shield.DRL, Arduino_FPGA_Shield.GBL, Arduino_FPGA_Shield.GBO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]
2014-05-02 Modified via dia on CSP to 10mil
    Modified the diameter of the vias on the QFN regulator and increased
    hole dia from 2mm to 2.54mm to lower board fab cost.
    [Arduino_FPGA_Shield.DRL, Arduino_FPGA_Shield.GBL, Arduino_FPGA_Shield.GBO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]
2014-05-02 Cosmetic Schematic Changes & PDFs
    Uploaded new PDFs and some cosmetic changes to the PDFs.
    [Arduino FPGA Top-Level Interface.SchDoc, Arduino_FPGA_Shield.PcbDoc]
2014-05-02 Mfg Clearance Cleanup
    Needed to make some small tweaks to deal with the mfg clearances which,
    due to rounding, were 0.00499" instead of the standard 5 mils.
    [Arduino_FPGA_Shield.DRL, Arduino_FPGA_Shield.GBL, Arduino_FPGA_Shield.GBO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]
2014-05-06 Added status LED for programming
    Added a status LED sheet to provide some feedback after programming.
    Includes jumper to enable feedback back to Arduino board via digital pin
    7 on Arduino connector
    [Arduino - FPGA Development Board.PrjPcb, Arduino FPGA Power.SchDoc, Arduino FPGA Top-Level Interface.SchDoc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]
2014-07-04 Functional Improvements Overhaul
    First revision worked well though this adds features like a dipswitch,
    some LEDs on the board (User and Status), a pushbutton that can be used
    as a reset or just additional I/F element. Also renamed JTAG port
    signals for Soft_JTAG chain, moved ICSP header for alignment to Arduino,
    cosmetic (silkscreen) improvements to PCB, added some labels to top
    level schematic to improve clarity.
    [AP2114H-3.3TRG1.SchLib, Arduino - FPGA Development Board.PrjPcb, Arduino FPGA Design.SchDoc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]
2014-07-04 Deleting old schematic directory
    Replaced with Design Documents comprehensive directory
    [Arduino_FPGA_Shield.PcbDoc, FPGA - XC6SLX9-2TQG144C.schdoc]
2014-08-17 Uploading final files - rev 2
    [Arduino - FPGA Development Board.PrjPcb, Arduino FPGA Design.SchDoc, Arduino FPGA SPI MUX.SchDoc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]
2014-12-11 Uploading Simple FPGA Example to Repo
    [HelloWorldSCH.sch, HelloWorldSCH_pad.csv]
2014-12-19 upload examples
    [Arduino - FPGA Development Board.PrjPcb]
2015-06-29 Updating for better programming flow
    A few minor tweaks to get this working with web end of web deployed FW
    updater.
    [Arduino - FPGA Development Board.PrjPcb, Arduino FPGA Design.SchDoc, Arduino FPGA Power.SchDoc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]
2015-06-30 Component parameter changes
    No FFF modifications, only parametric changes and updates to output
    generator (CAM) to produce all files locally in a more sensible way.
    [ADTSM32RVTR.PcbLib, ADTSM32RVTR.SchLib, Arduino - FPGA Development Board.PrjPcb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]
